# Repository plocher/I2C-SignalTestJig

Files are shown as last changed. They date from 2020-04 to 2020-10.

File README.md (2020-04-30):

# I2C-SignalTestJig
## License: CERN Open Hardware Licence v1.2

Test Jig for simple signal panels

An I2C slave board that drives 6x signal head drivers (effectively 3x IOB-Signal circuits)
in a form factor that mimics the panelization spacing of the simple signal boards.

This allows bulk testing after fabrication of an entire board in 2 (or 4) operations 
  * align a board with the pogo pins
  * press down on pins
  * observe the correct operation of the heads
     * mark any defective units
  * move panel to next set of contacts & repeat

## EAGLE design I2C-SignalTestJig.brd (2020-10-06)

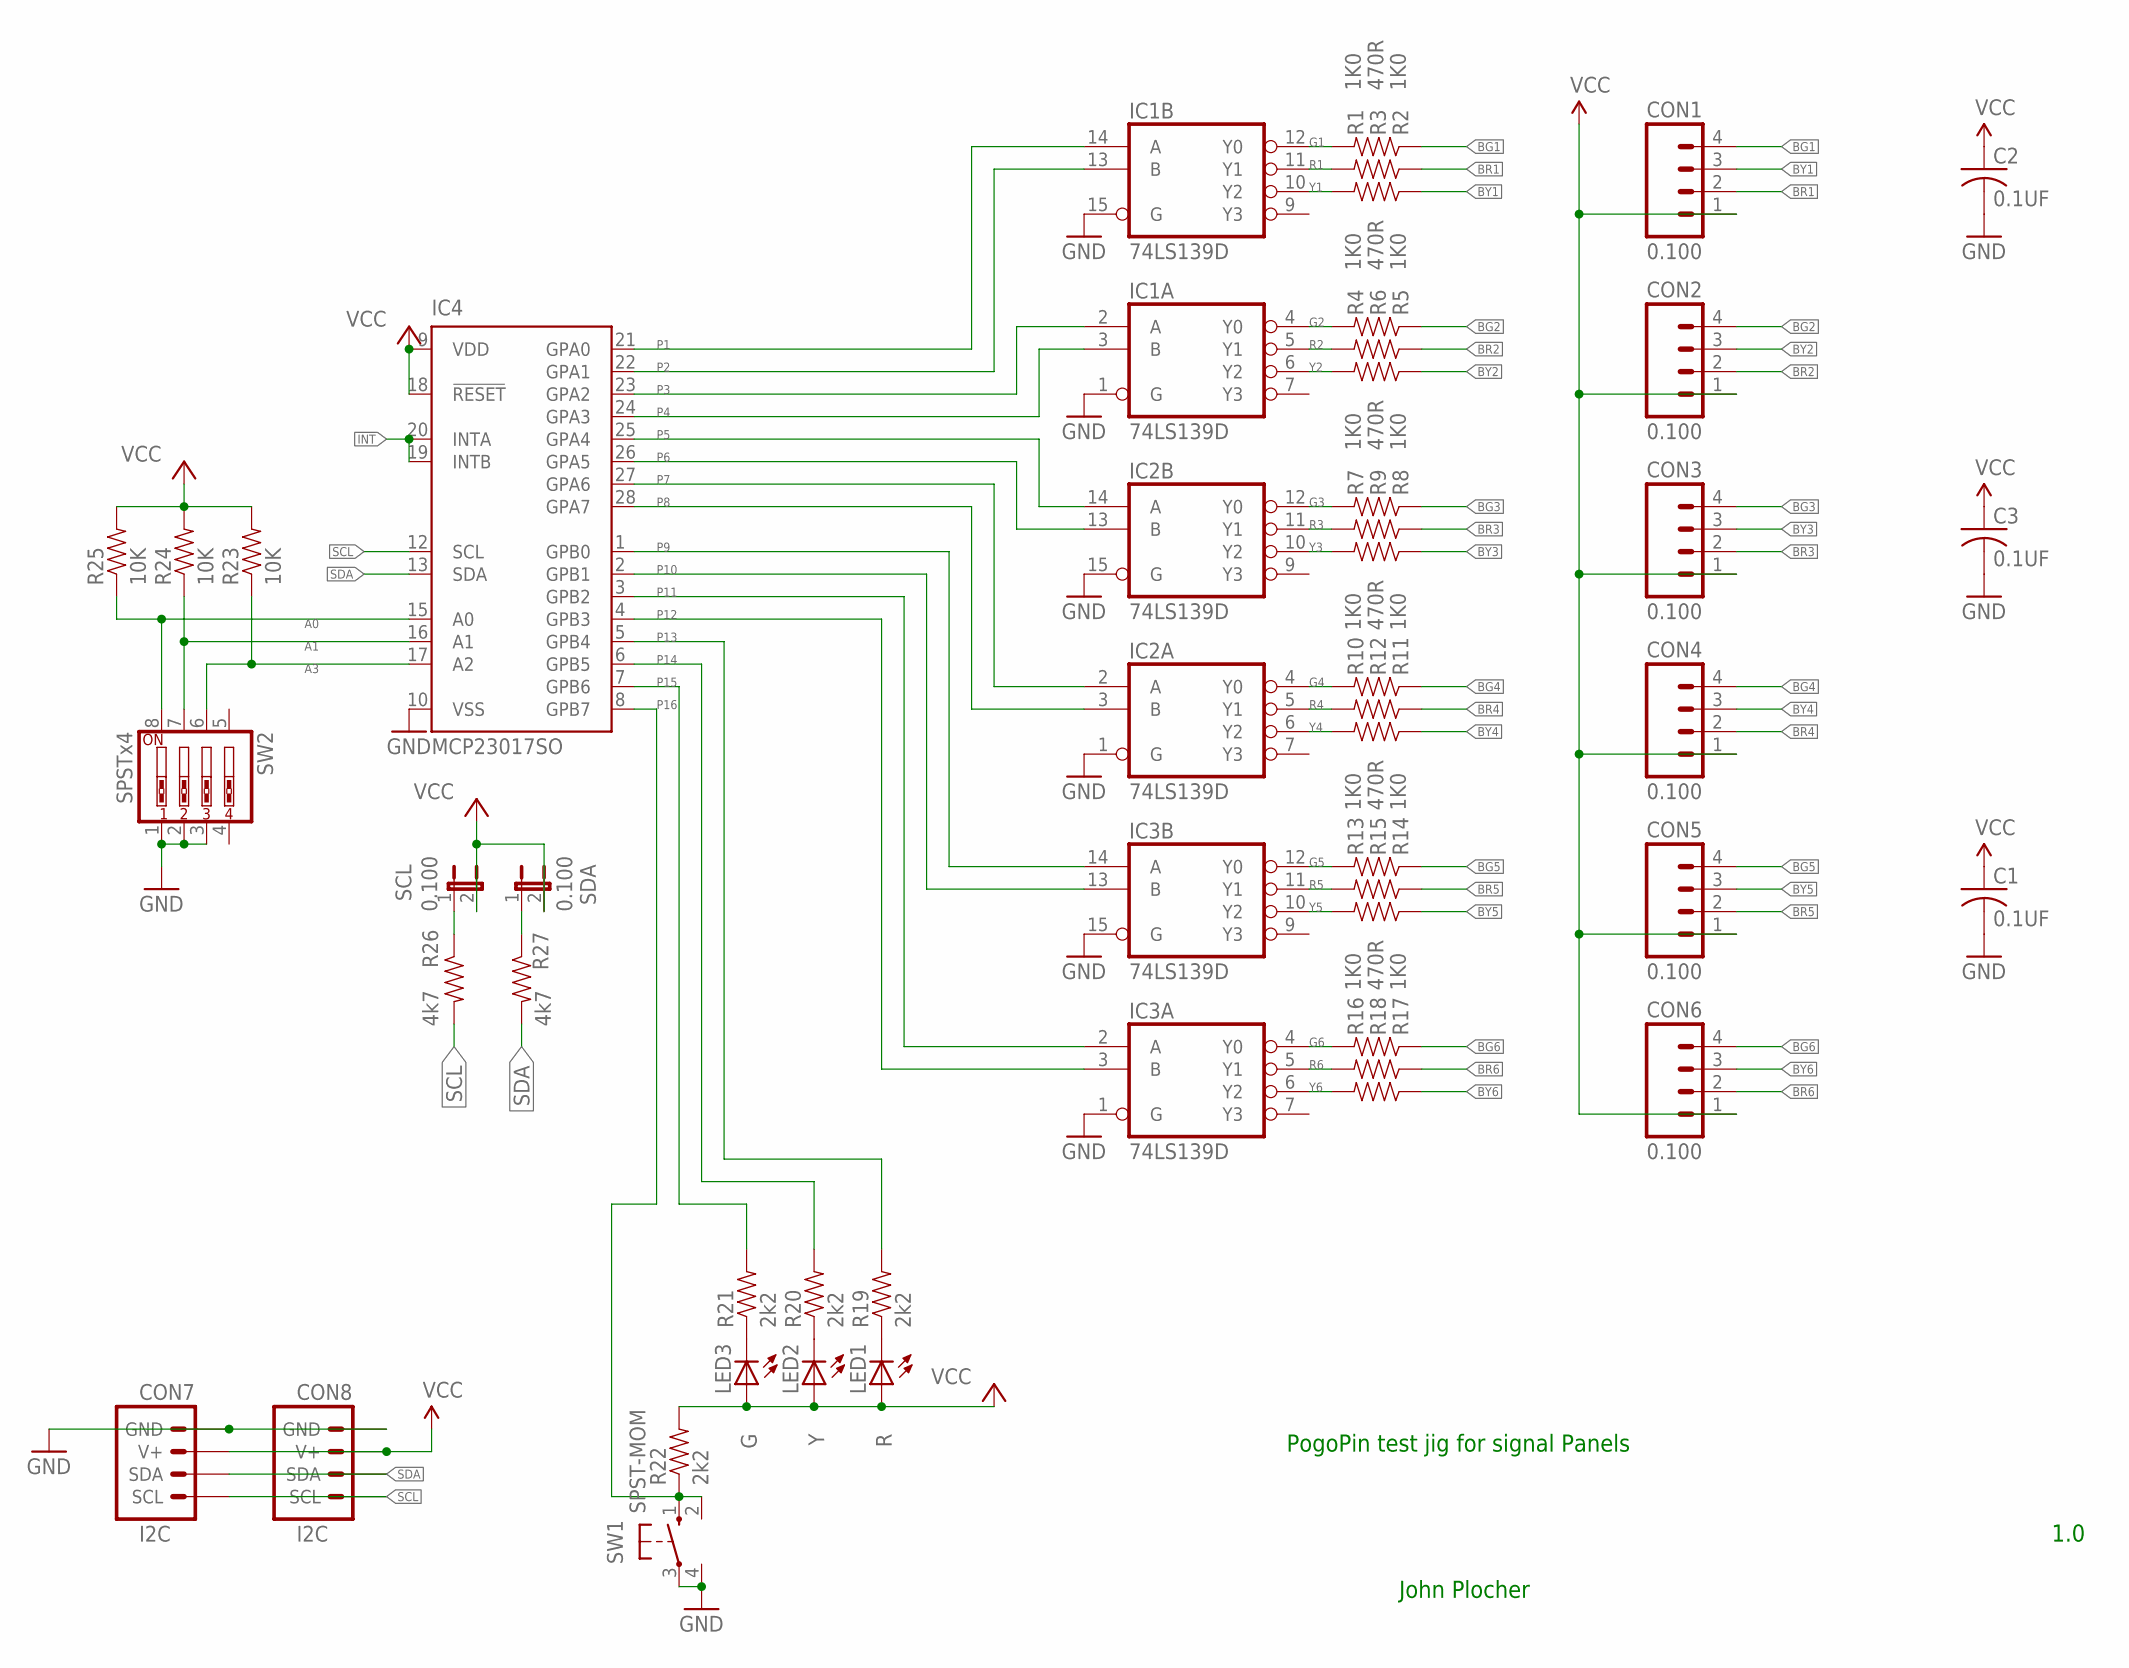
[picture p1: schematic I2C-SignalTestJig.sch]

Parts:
C1, C2, C3: 0.1UF; 0603-CAP
CON1, CON2, CON3, CON4, CON5, CON6: 0.100; 1X04_LOCK
CON7, CON8: I2C; I2C-L
IC1, IC2, IC3: 74LS139D; SO16
IC4: MCP23017SO; SO28W
LED1: R; 0603-LED
LED2: Y; 0603-LED
LED3: G; 0603-LED
R1, R2, R4, R5, R7, R8, R10, R11, R13, R14, R16, R17: 1K0; 0805-RES
R3, R6, R9, R12, R15, R18: 470R; 0805-RES
R19, R20, R21, R22: 2k2; 0603-RES
R23, R24, R25: 10K; 0603-RES
R26, R27: 4k7; 0603-RES
SCL: 0.100; 1X02_LOCK
SDA: 0.100; 1X02_LOCK
SW1: SPST-MOM; 4P-PTH-6.0X6.0X5.0H
SW2: SPSTx4; EDG-04

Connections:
!INT: IC4.19 (INTB), IC4.20 (INTA)
A0: IC4.15 (A0), R25.1, SW2.8
A1: IC4.16 (A1), R24.1, SW2.7
A3: IC4.17 (A2), R23.1, SW2.6
BG1: CON1.4, R1.1
BG2: CON2.4, R4.1
BG3: CON3.4, R7.1
BG4: CON4.4, R10.1
BG5: CON5.4, R13.1
BG6: CON6.4, R16.1
BR1: CON1.2, R3.1
BR2: CON2.2, R6.1
BR3: CON3.2, R9.1
BR4: CON4.2, R12.1
BR5: CON5.2, R15.1
BR6: CON6.2, R18.1
BY1: CON1.3, R2.1
BY2: CON2.3, R5.1
BY3: CON3.3, R8.1
BY4: CON4.3, R11.1
BY5: CON5.3, R14.1
BY6: CON6.3, R17.1
G1: IC1.12 (Y0), R1.2
G2: IC1.4 (Y0), R4.2
G3: IC2.12 (Y0), R7.2
G4: IC2.4 (Y0), R10.2
G5: IC3.12 (Y0), R13.2
G6: IC3.4 (Y0), R16.2
GND: C1.2, C2.2, C3.2, CON7.GND, CON7.GND@1 (GND), CON8.GND, CON8.GND@1 (GND), IC1.1 (G), IC1.8 (GND), IC1.15 (G), IC2.1 (G), IC2.8 (GND), IC2.15 (G), IC3.1 (G), IC3.8 (GND), IC3.15 (G), IC4.10 (VSS), SW1.3, SW1.4 (P1), SW2.1, SW2.2, SW2.3
unnamed: LED3.C, R21.1
unnamed: LED2.C, R20.1
unnamed: LED1.C, R19.1
unnamed: R26.1, SCL.1
unnamed: R27.1, SDA.1
P1: IC1.14 (A), IC4.21 (GPA0)
P2: IC1.13 (B), IC4.22 (GPA1)
P3: IC1.2 (A), IC4.23 (GPA2)
P4: IC1.3 (B), IC4.24 (GPA3)
P5: IC2.14 (A), IC4.25 (GPA4)
P6: IC2.13 (B), IC4.26 (GPA5)
P7: IC2.2 (A), IC4.27 (GPA6)
P8: IC2.3 (B), IC4.28 (GPA7)
P9: IC3.14 (A), IC4.1 (GPB0)
P10: IC3.13 (B), IC4.2 (GPB1)
P11: IC3.2 (A), IC4.3 (GPB2)
P12: IC3.3 (B), IC4.4 (GPB3)
P13: IC4.5 (GPB4), R19.2
P14: IC4.6 (GPB5), R20.2
P15: IC4.7 (GPB6), R21.2
P16: IC4.8 (GPB7), R22.1, SW1.1 (S), SW1.2 (S1)
R1: IC1.11 (Y1), R3.2
R2: IC1.5 (Y1), R6.2
R3: IC2.11 (Y1), R9.2
R4: IC2.5 (Y1), R12.2
R5: IC3.11 (Y1), R15.2
R6: IC3.5 (Y1), R18.2
SCL: CON7.SCL, CON7.SCL@1 (SCL), CON8.SCL, CON8.SCL@1 (SCL), IC4.12 (SCL), R26.2
SDA: CON7.SDA, CON7.SDA@1 (SDA), CON8.SDA, CON8.SDA@1 (SDA), IC4.13 (SDA), R27.2
VCC: C1.1, C2.1, C3.1, CON1.1, CON2.1, CON3.1, CON4.1, CON5.1, CON6.1, CON7.V+, CON7.V+@1 (V+), CON8.V+, CON8.V+@1 (V+), IC1.16 (VCC), IC2.16 (VCC), IC3.16 (VCC), IC4.9 (VDD), IC4.18 (!RESET), LED1.A, LED2.A, LED3.A, R22.2, R23.2, R24.2, R25.2, SCL.2, SDA.2
Y1: IC1.10 (Y2), R2.2
Y2: IC1.6 (Y2), R5.2
Y3: IC2.10 (Y2), R8.2
Y4: IC2.6 (Y2), R11.2
Y5: IC3.10 (Y2), R14.2
Y6: IC3.6 (Y2), R17.2

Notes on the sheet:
PogoPin test jig for signal Panels
John Plocher
1.0

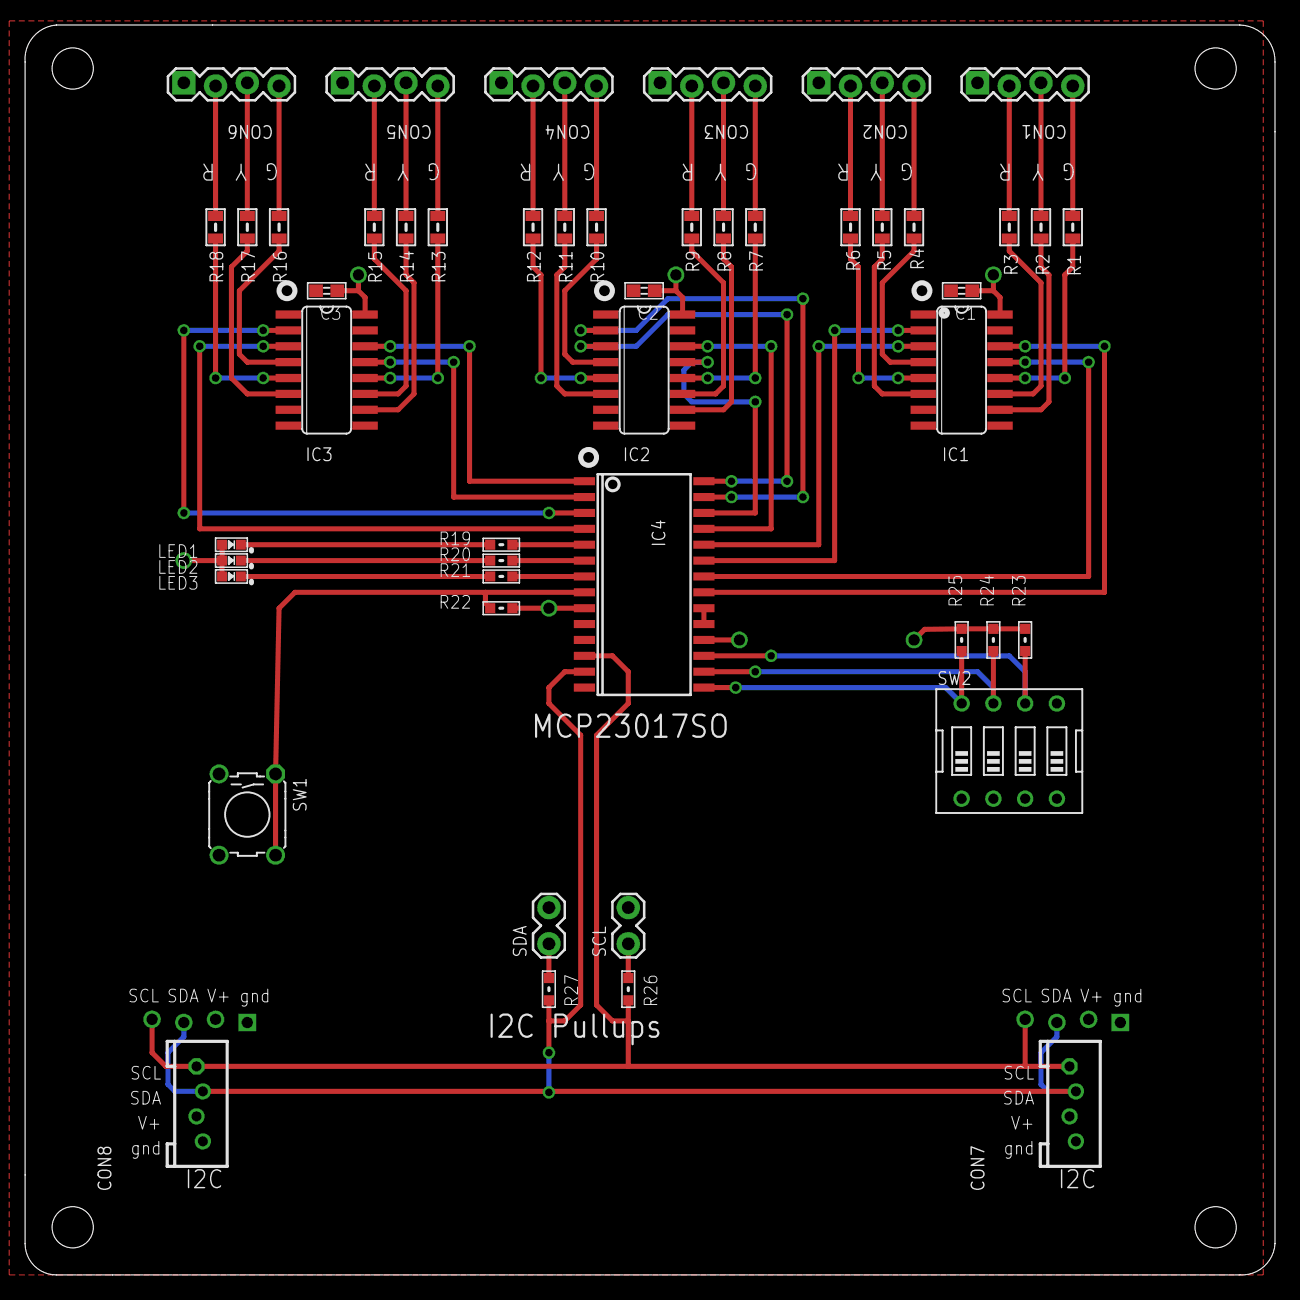
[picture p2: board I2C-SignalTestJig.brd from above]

Board: 2 copper layers, 100.0 x 100.0 mm, 50 parts (0 on the bottom side), 65 nets.

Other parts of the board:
BOARD1: BOARD; BOARD-SEEED10X10-NOHOLES

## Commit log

2020-04-30 Initial version
    [I2C-SignalTestJig.brd, I2C-SignalTestJig.sch]
2020-10-05 added values for connectors
    [I2C-SignalTestJig.brd, I2C-SignalTestJig.sch]
2020-10-06 normalized values
    [I2C-SignalTestJig.brd, I2C-SignalTestJig.sch]
